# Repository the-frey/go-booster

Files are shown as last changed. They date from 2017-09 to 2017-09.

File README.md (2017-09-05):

# Go! Booster pedal

Project files for the Go! Booster. Note that the template in the board file is for the standard drilling that I use - you can ignore it, as it's not a visible layer for the sake of board export or manufacturing setup.

Hopefully at some point I will remember to upload an offboard wiring mini PCB for the 3PDT switch you will need.

The 3mm LED in the opamp feedback path will add some clipping; a heavy clipping diode like a germanium diode might cause too much signal loss, so if you're going to experiment, then socket the diode.

I personally tend to leave it blank; the production Go! doesn't have anything in that spot.

Finally, obviously you can wire the treble control up to an actual pot. This PCB should just about fit in a 1590A, but I choose to put it in a roomier 125B as I prefer the form factor.

Happy hacking!

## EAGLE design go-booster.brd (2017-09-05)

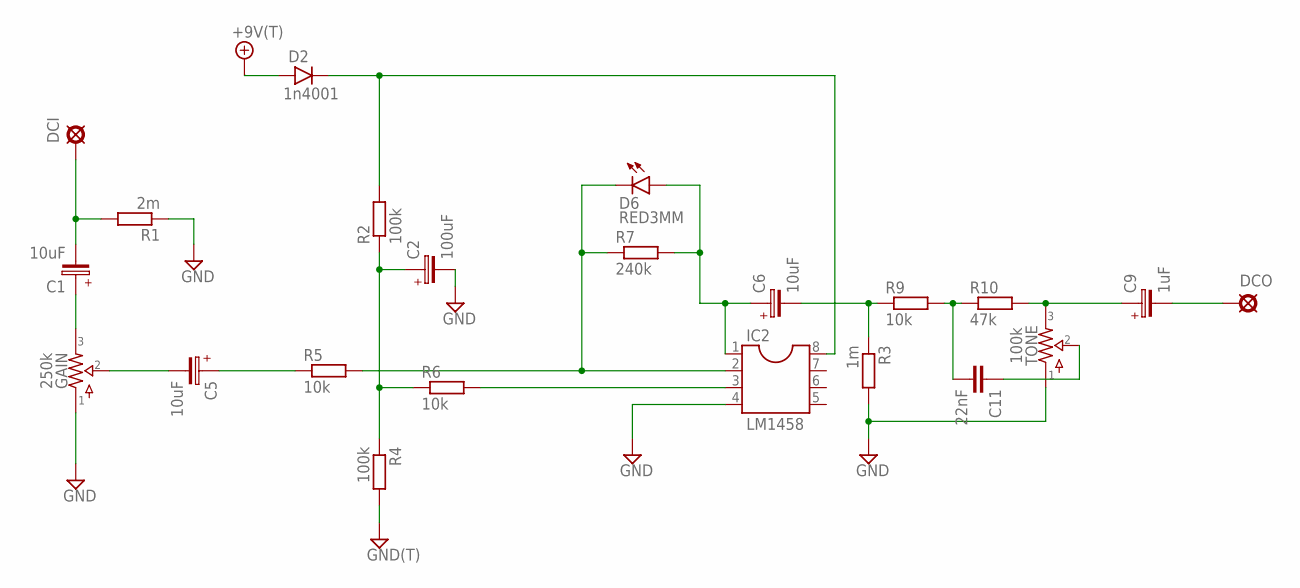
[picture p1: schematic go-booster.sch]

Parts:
+9V2: +9V(T); SQUARE
C1, C5, C6: 10uF; 050_020_1
C2: 100uF; 050_020_1
C9: 1uF; 050_020_1
C11: 22nF; 072X025
D2: 1n4001; DO41-4
D6: RED3MM; LED3MM
DCI: IN; OCTOGON
DCO: OUT; OCTOGON
GAIN: 250k; 16MM_CENTERMOUNT
GND11: GND(T); SQUARE
IC2: LM1458; SOCKET-08
R1: 2m; 0207/10
R2, R4: 100k; 0207/10
R3: 1m; 0207/10
R5, R6, R9: 10k; 0207/10
R7: 240k; 0207/10
R10: 47k; 0207/10
TONE: 100k; 2262_TRIM

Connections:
+9V: +9V2.1, D2.A
GND: C2.-, GAIN.1, GND11.1, IC2.4, R1.1, R3.2, R4.2, TONE.1
unnamed: C1.+, GAIN.3
unnamed: C1.-, DCI.1, R1.2
unnamed: D2.C, IC2.8, R2.2
unnamed: D6.K (C), IC2.2, R5.2, R7.1
unnamed: IC2.3, R6.2
unnamed: C6.+, D6.A, IC2.1, R7.2
unnamed: C5.-, GAIN.2
unnamed: C2.+, R2.1, R4.1, R6.1
unnamed: C6.-, R3.1, R9.1
unnamed: C5.+, R5.1
unnamed: C9.-, DCO.1
unnamed: C11.2, R9.2, R10.1
unnamed: C9.+, R10.2, TONE.3
unnamed: C11.1, TONE.2

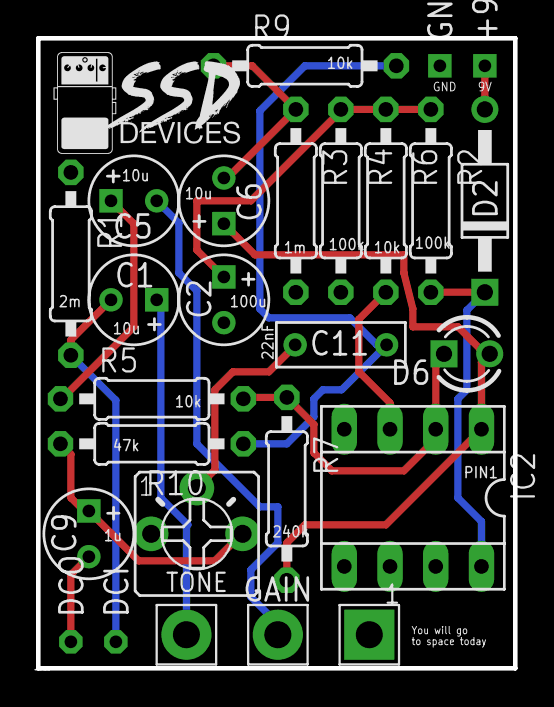
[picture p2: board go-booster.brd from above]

Board: 2 copper layers, 26.5 x 35.0 mm, 24 parts (0 on the bottom side), 16 nets.
